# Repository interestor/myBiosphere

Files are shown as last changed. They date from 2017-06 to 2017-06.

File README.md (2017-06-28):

# myBiosphere
It is open source project that make device to make closed ecosystem on a desktop.

parts and material list is here.
http://archive.fabacademy.org/archives/2017/fablabkitakagaya/students/210/final_project.html

<br />

## files 
- code for Arduino[myBiosphere_Arduino.ino]
- code for Processing[myBiosphere_Processing.pde]
- processor boad design
- power board design
- stand's 3d design file
- branch's 3d design file
- island(pod)'s 3d design file
- cap's 3d design file
- heater's mould 3d design file
- ring's 3d design file

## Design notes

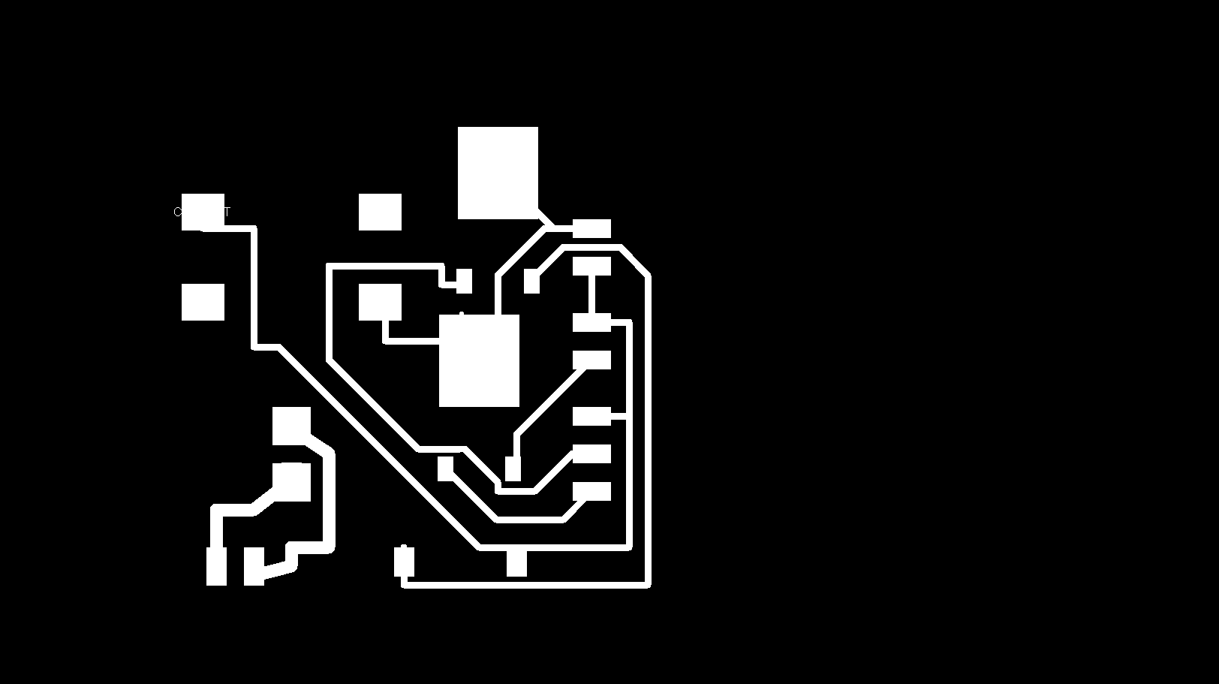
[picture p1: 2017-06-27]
power_boad/output_board_ver3.png

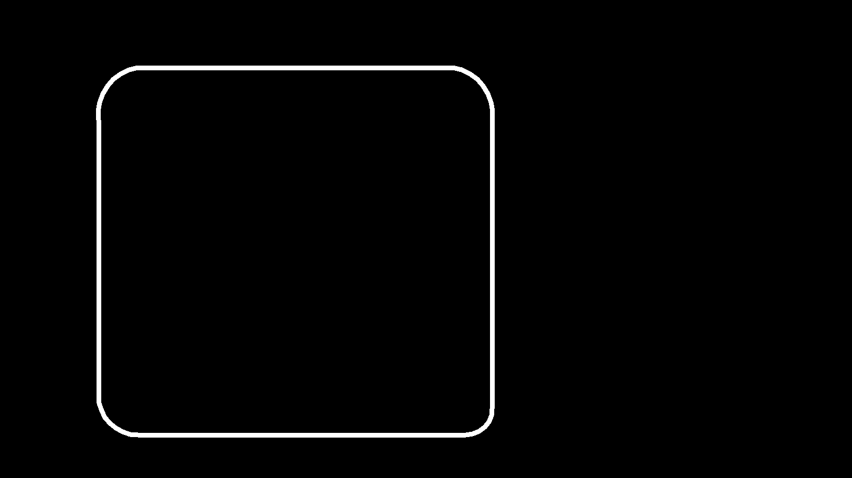
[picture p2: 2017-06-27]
power_boad/output_board_ver3_interior.png

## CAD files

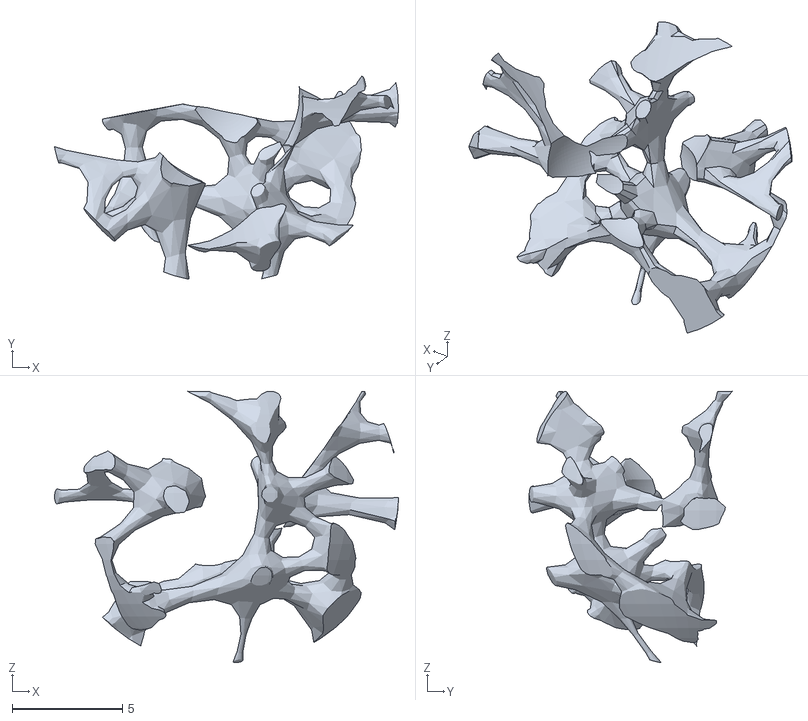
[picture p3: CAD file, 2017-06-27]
branch/branch_7.2cm-16cm_part2.stl
15.6 x 9.22 x 12.3

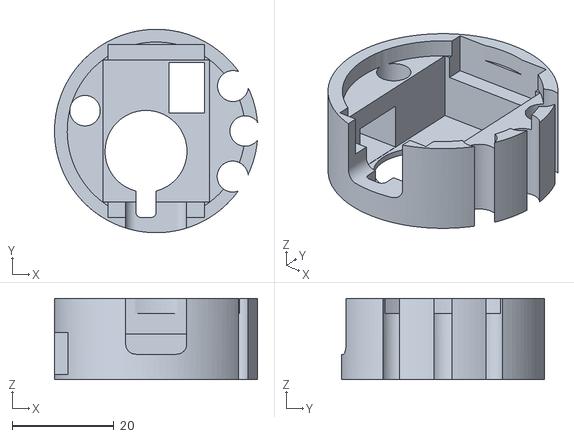
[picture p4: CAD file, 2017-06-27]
cap/sensor_cap_ver6.stl
39.9 x 40.0 x 16.0

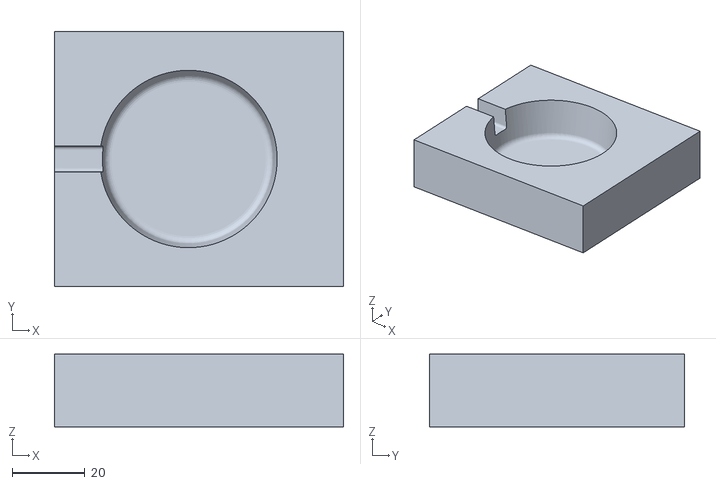
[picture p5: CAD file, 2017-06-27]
heater_mould/heater_mould.stl
79.2 x 70.0 x 20.0

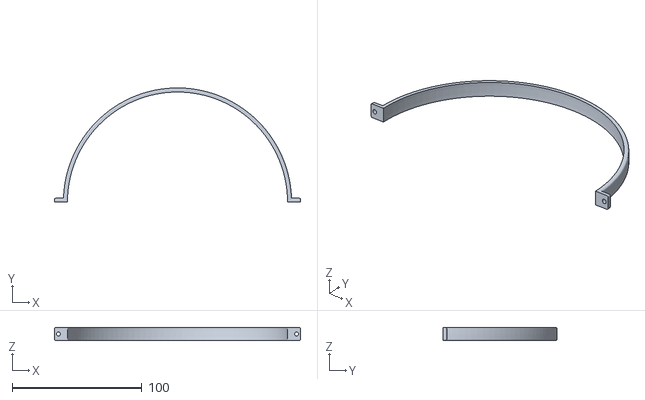
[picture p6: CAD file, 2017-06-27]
ring/equator_0.stl
189.7 x 88.0 x 10.0

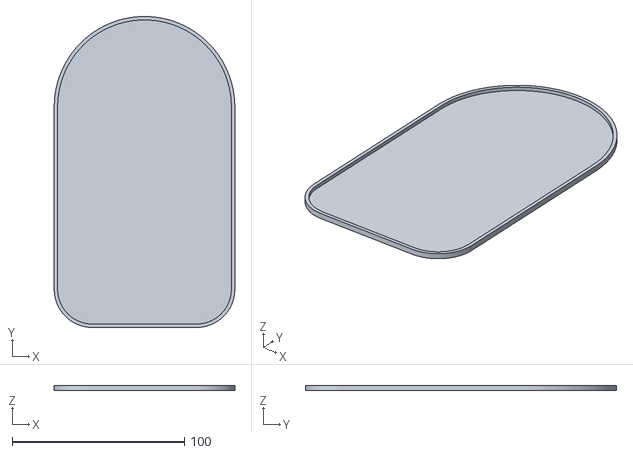
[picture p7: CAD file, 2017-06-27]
stand/stand_buttom.stl
105.0 x 180.8 x 3.03

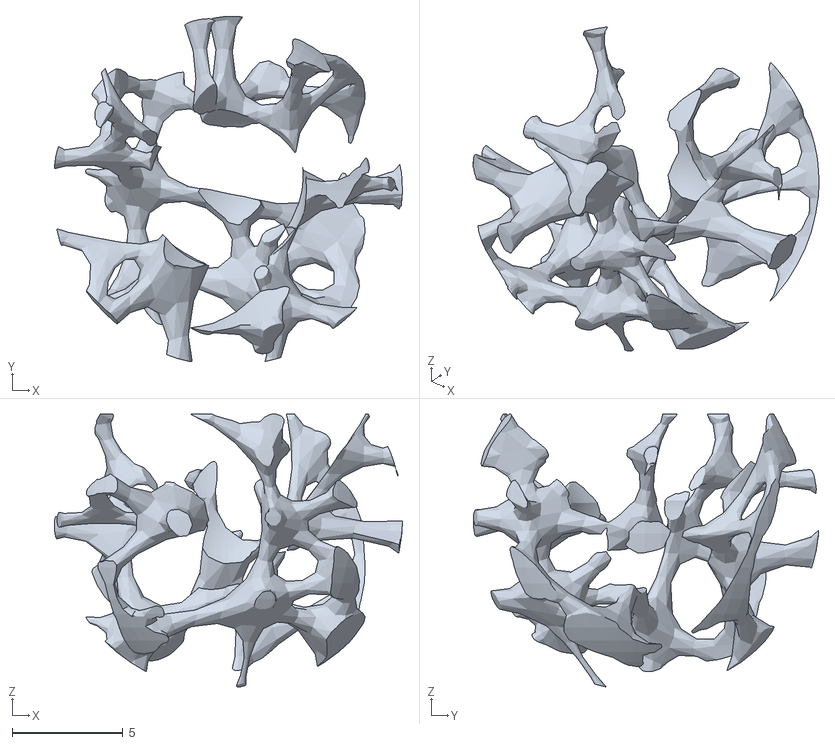
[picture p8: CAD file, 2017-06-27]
branch/branch_7.2cm-16cm.stl
15.7 x 15.6 x 12.3

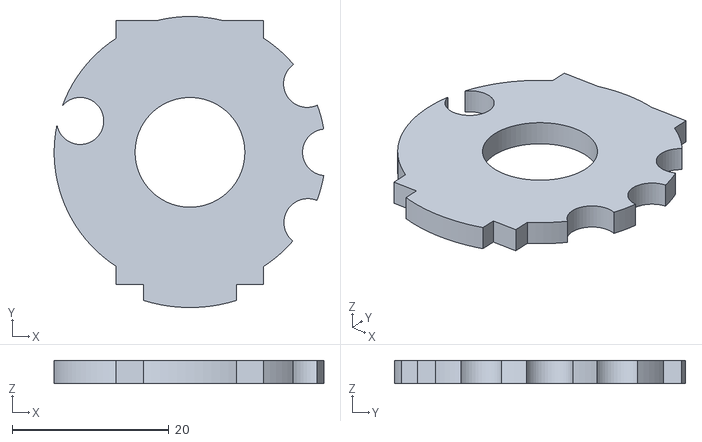
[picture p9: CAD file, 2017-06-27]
cap/sensor_cap_cap_ver6.stl
34.4 x 37.1 x 2.97

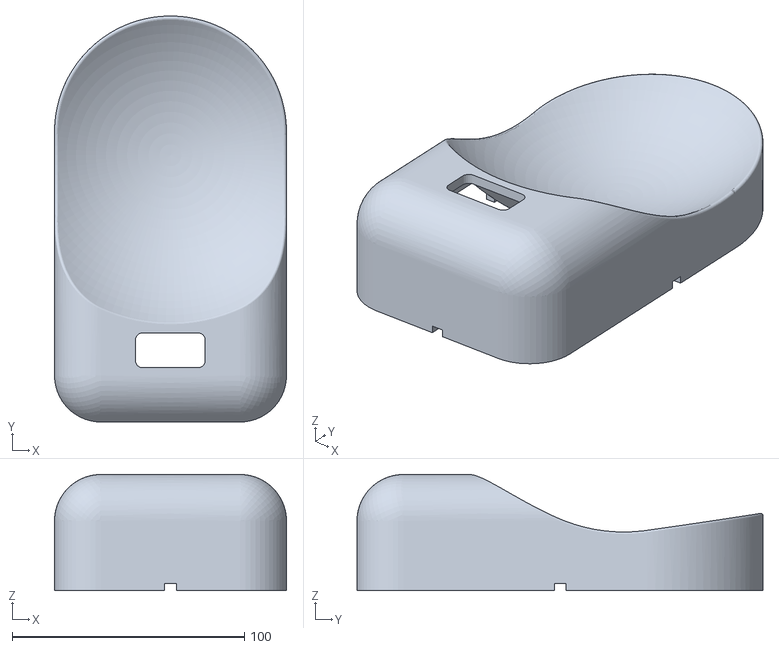
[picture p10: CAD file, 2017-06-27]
stand/stand_ver6.stl
100.0 x 175.0 x 50.0

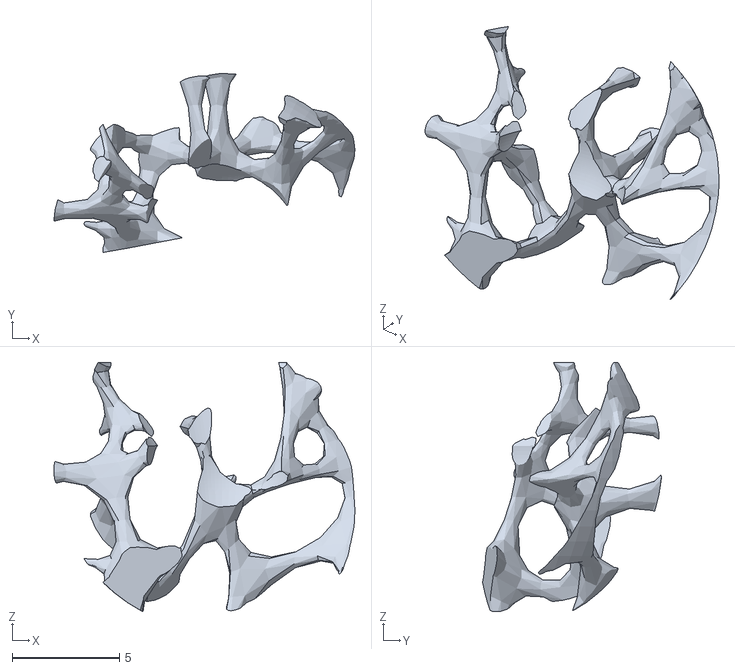
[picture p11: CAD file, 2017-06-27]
branch/branch_7.2cm-16cm_part1.stl
14.0 x 8.35 x 11.6

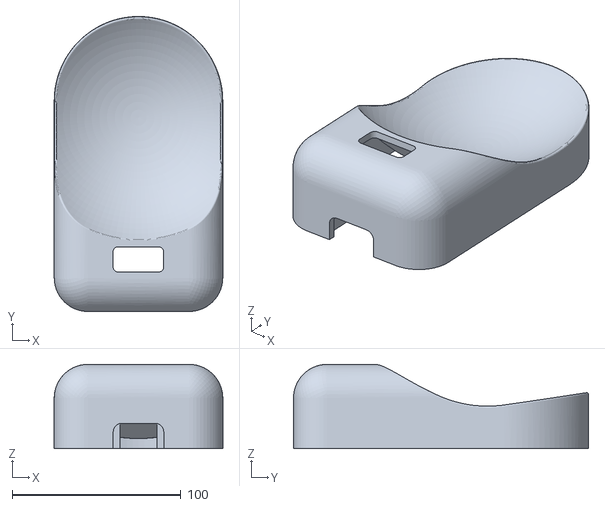
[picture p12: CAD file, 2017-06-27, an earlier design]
stand/stand_ver5.stl
100.0 x 175.0 x 50.0

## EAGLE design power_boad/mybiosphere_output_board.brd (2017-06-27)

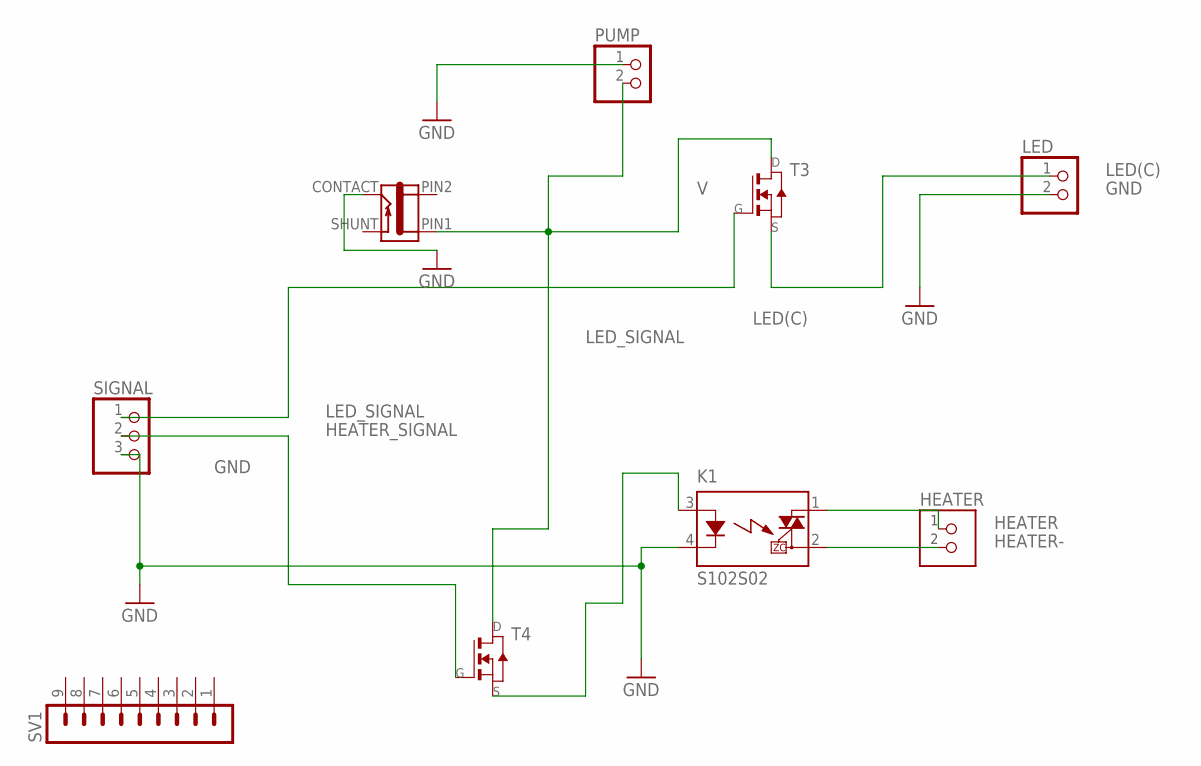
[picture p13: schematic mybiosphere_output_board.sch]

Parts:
HEATER: TERM-1X02-FABLAB; ED555DS-2DS
J1: JACK-2.1MM; PJ-002AH-SMT
K1: S102S02; S202S02
LED: PINHD-1X2/90; 1X02/90
PUMP: PINHD-1X2/90; 1X02/90
SIGNAL: PINHD-1X3; 1X03
SV1: MA09-1
T3, T4: NMOSFETTO252; TO252

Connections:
GND: J1.CONTACT, K1.4 (K), LED.2, PUMP.1, SIGNAL.3
HEATER: HEATER.1, K1.1 (DS1)
HEATER-: HEATER.2, K1.2 (DS2)
HEATER_SIGNAL: SIGNAL.2, T4.1 (G)
LED(C): LED.1, T3.2 (S)
LED_SIGNAL: SIGNAL.1, T3.1 (G)
unnamed: K1.3 (A), T4.2 (S)
PIN2: J1.PIN2
SHUNT: J1.SHUNT
V: J1.PIN1, PUMP.2, T3.3 (D), T4.3 (D)

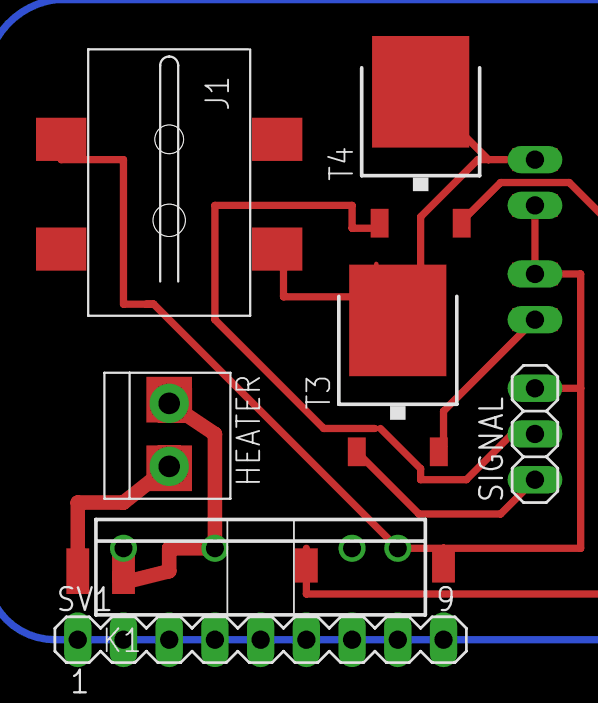
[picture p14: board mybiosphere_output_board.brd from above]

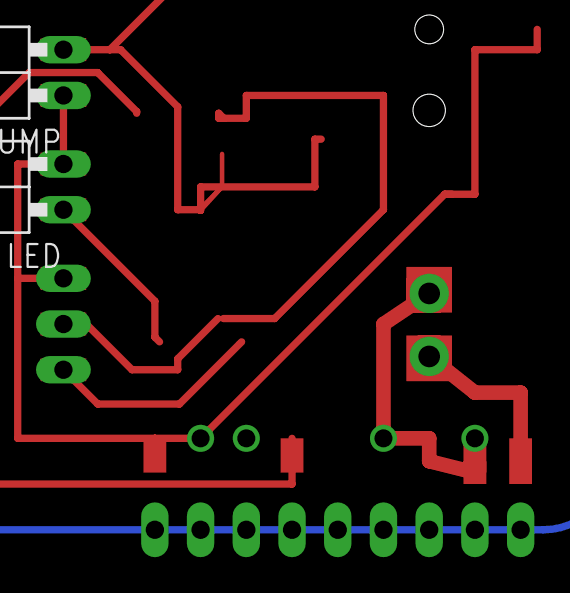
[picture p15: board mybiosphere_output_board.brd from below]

Board: 2 copper layers, 9 parts (2 on the bottom side), 8 nets.

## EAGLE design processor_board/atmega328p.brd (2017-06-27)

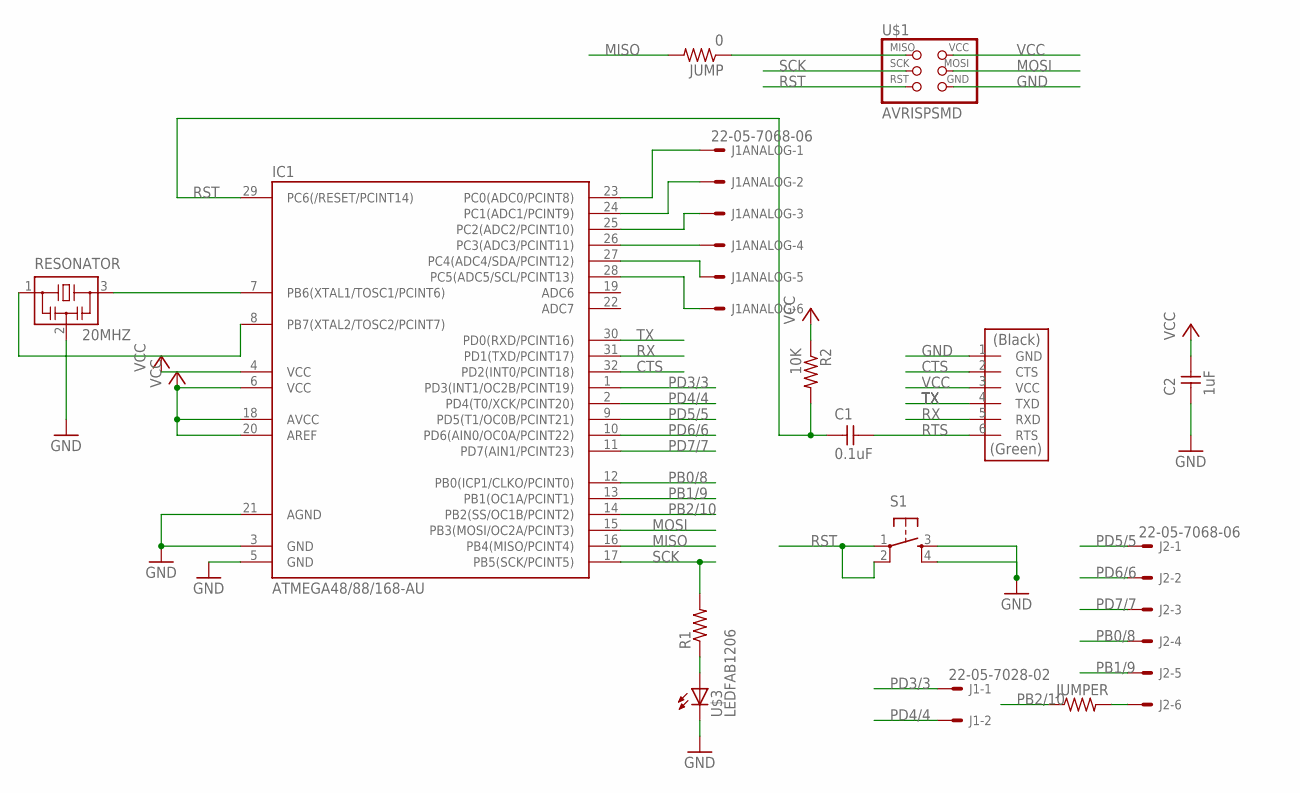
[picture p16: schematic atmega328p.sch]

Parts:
C1: 0.1uF; C1206FAB
C2: 1uF; C1206FAB
IC1: ATMEGA48/88/168-AU; TQFP32-08
J1: 22-05-7028-02; 7395-02
J1ANALOG, J2: 22-05-7068-06; 7395-06
JUMP: 0; R1206FAB
JUMPER: RES-US1206FAB; R1206FAB
R1: RES-US1206FAB; R1206FAB
R2: 10K; R1206FAB
RESONATOR: 20MHZ; EFOBM
S1: 6MM_SWITCH6MM_SWITCH; 6MM_SWITCH
U$1: AVRISPSMD; 2X03SMD
U$2: FTDI-SMD-HEADER; 1X06SMD
U$3: LEDFAB1206; LED1206FAB

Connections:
CTS: IC1.32 (PD2(INT0/PCINT18)), U$2.2 (CTS)
GND: C2.1, IC1.3 (GND), IC1.5 (GND), IC1.21 (AGND), RESONATOR.2, S1.3 (S), S1.4 (S1), U$1.6 (GND), U$2.1 (GND), U$3.2 (C)
MISO: IC1.16 (PB4(MISO/PCINT4)), JUMP.2
MOSI: IC1.15 (PB3(MOSI/OC2A/PCINT3)), U$1.4 (MOSI)
unnamed: IC1.7 (PB6(XTAL1/TOSC1/PCINT6)), RESONATOR.3
unnamed: IC1.8 (PB7(XTAL2/TOSC2/PCINT7)), RESONATOR.1
unnamed: JUMP.1, U$1.1 (MISO)
unnamed: J2.6, JUMPER.2
unnamed: IC1.23 (PC0(ADC0/PCINT8)), J1ANALOG.1
unnamed: R1.1, U$3.1 (A)
unnamed: IC1.24 (PC1(ADC1/PCINT9)), J1ANALOG.2
unnamed: IC1.25 (PC2(ADC2/PCINT10)), J1ANALOG.3
unnamed: IC1.26 (PC3(ADC3/PCINT11)), J1ANALOG.4
unnamed: IC1.27 (PC4(ADC4/SDA/PCINT12)), J1ANALOG.5
unnamed: IC1.28 (PC5(ADC5/SCL/PCINT13)), J1ANALOG.6
PB0/8: IC1.12 (PB0(ICP1/CLKO/PCINT0)), J2.4
PB1/9: IC1.13 (PB1(OC1A/PCINT1)), J2.5
PB2/10: IC1.14 (PB2(SS/OC1B/PCINT2)), JUMPER.1
PD3/3: IC1.1 (PD3(INT1/OC2B/PCINT19)), J1.1
PD4/4: IC1.2 (PD4(T0/XCK/PCINT20)), J1.2
PD5/5: IC1.9 (PD5(T1/OC0B/PCINT21)), J2.1
PD6/6: IC1.10 (PD6(AIN0/OC0A/PCINT22)), J2.2
PD7/7: IC1.11 (PD7(AIN1/PCINT23)), J2.3
RST: C1.1, IC1.29 (PC6(/RESET/PCINT14)), R2.2, S1.1, S1.2 (P1), U$1.5 (RST)
RTS: C1.2, U$2.6 (RTS)
RX: IC1.31 (PD1(TXD/PCINT17)), U$2.5 (RXD)
SCK: IC1.17 (PB5(SCK/PCINT5)), R1.2, U$1.3 (SCK)
TX: IC1.30 (PD0(RXD/PCINT16)), U$2.4 (TXD)
VCC: C2.2, IC1.4 (VCC), IC1.6 (VCC), IC1.18 (AVCC), IC1.20 (AREF), R2.1, U$1.2 (VCC), U$2.3 (VCC)

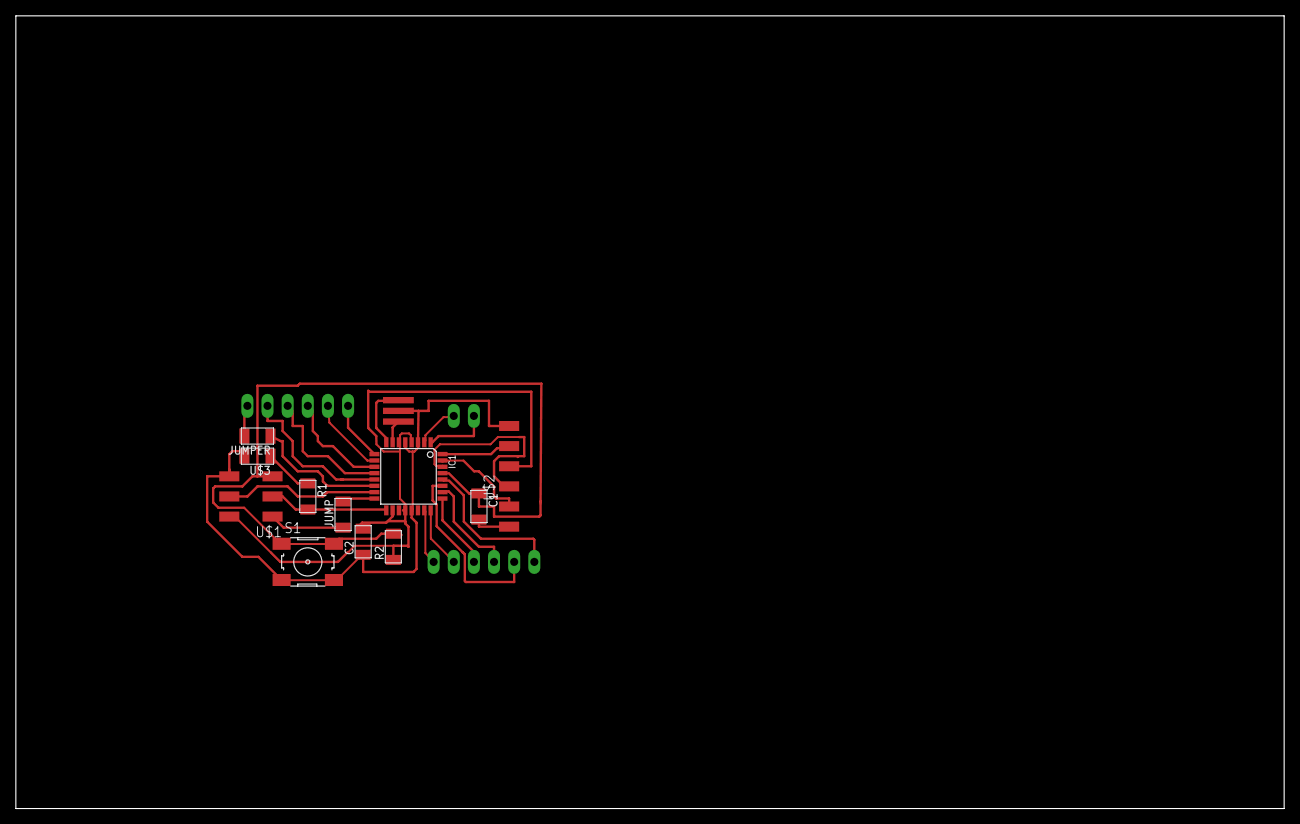
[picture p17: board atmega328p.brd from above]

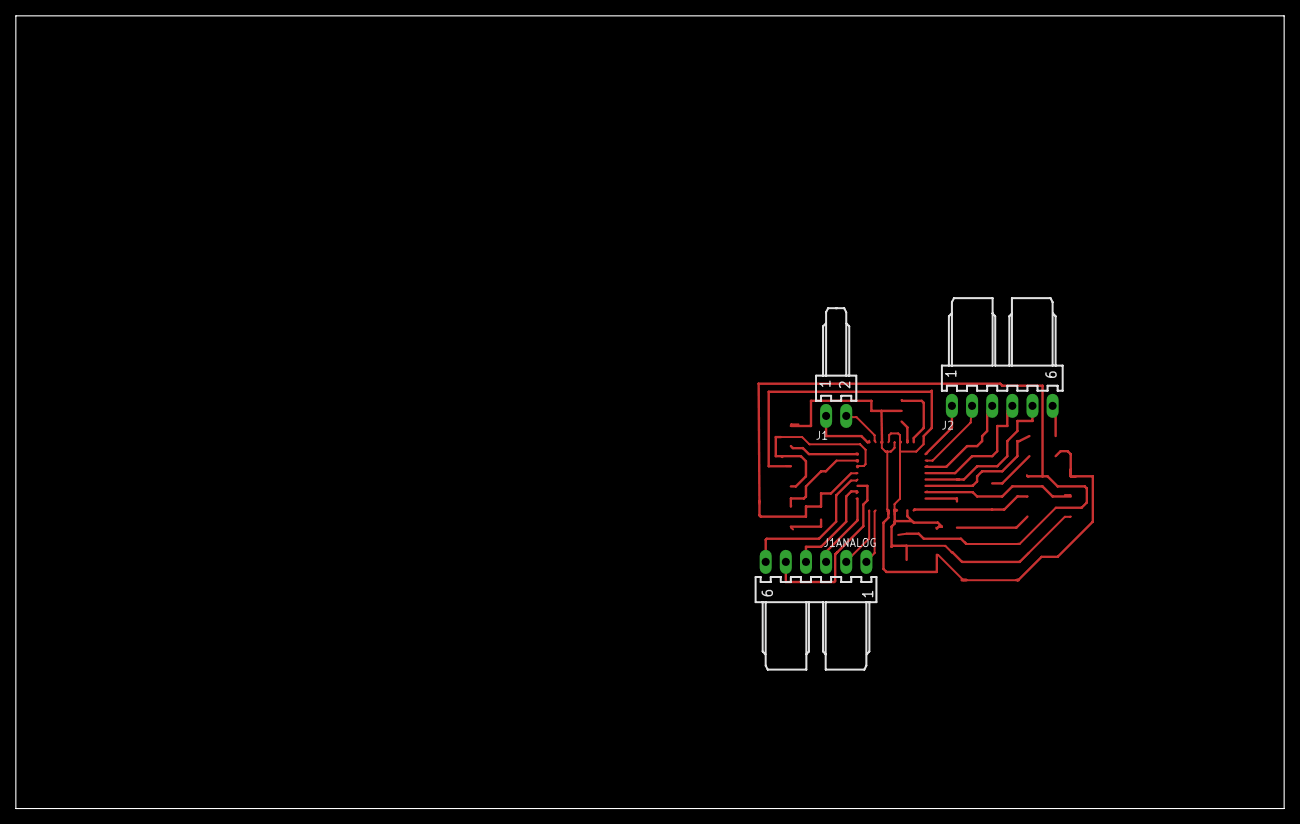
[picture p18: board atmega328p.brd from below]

Board: 2 copper layers, 160.0 x 100.0 mm, 15 parts (3 on the bottom side), 29 nets.

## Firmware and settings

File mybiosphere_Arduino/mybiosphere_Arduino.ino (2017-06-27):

#define TEMP_SENSORPIN  (2)
#define LIGHT_SENSORPIN  (1)
#define LED_PIN 4
#define CO2_PWM 3 //CO2
#define HEATER_PIN (5)


int temp_val = 0;
float B=3435,T0=298.15,R0=10.0,R1=3.25,rr1,t;//for temprature

float v = 5;
float temp = 0;
float heat_on = 35;
float heat_off = heat_on + 100;
int light_on = 40;
int light_off = 40;
int break_co2_loop;

//for CO2
int prevVal = LOW;
long th, tl, h, l, ppm;

String recieve= "22.4,0,0,0";

void setup() {
  Serial.begin(9600);
  pinMode(LED_PIN, OUTPUT);
  pinMode(CO2_PWM, INPUT);
  pinMode(HEATER_PIN,OUTPUT);
    pinMode(13,OUTPUT);//////////////////test
  ppm=0;
}

void loop() {

 
 
 //mesuare temprature by AT-103
  temp_val = analogRead(TEMP_SENSORPIN);
  rr1=R1*temp_val/(1024.0-temp_val);
  t=1/(log(rr1/R0)/B+(1/T0));
  temp=(t-273.15);
 

  //mesure light by cds

  int light_val = analogRead( LIGHT_SENSORPIN );
  int light  = map(light_val, 0, 100, 0, 1023);


  //mesure CO2
  

  break_co2_loop=0;
  while( break_co2_loop < 2 ){

    long tt = millis();
    int myVal = digitalRead(CO2_PWM);

    if (myVal == HIGH) {
      if (myVal != prevVal) {
        h = tt;
        tl = h - l;
        prevVal = myVal;
      }
    }  
    else {
      if (myVal != prevVal) {
        l = tt;
        th = l - h;
        prevVal = myVal;
        ppm = 5000 * (th - 2) / (th + tl - 4);
        break_co2_loop++;
        if(break_co2_loop==2){
          
          Serial.print("temp,");//どこに入れる？
          Serial.print(temp);
          Serial.print(",");
          Serial.print("light,");
          Serial.print(light);
          Serial.print(",");
          Serial.println("CO2 ," + String(ppm));
        }
      }
    }
  }


///recieve threshold

while (Serial.available()) { // If data is available to read,
  recieve  = Serial.readStringUntil(';'); // read it and store it in val
 
  char recieve_c[255];
  recieve.toCharArray(recieve_c, 255);//文字列操作のためchar型に変換
  
  //,で分割してcharに格納
  char *heat_on_c = strtok(recieve_c,",");
  char *heat_off_c = strtok(NULL,",");  //2回目以降は第一引数はNULL
  char *light_on_c = strtok(NULL,","); 
  char *light_off_c = strtok(NULL,","); 

  
  //Serial.println(heat_on_c);//for debug
  //Serial.println(heat_off_c);
  //Serial.println(light_on_c);
  //Serial.println(light_off_c);
 
 //char からfloatに変換 
  heat_on = atof(heat_on_c);
  heat_off = atof(heat_off_c);
  light_on = atof(light_on_c);
  light_off = atof(light_off_c);

 delay(100); // Wait 100 milliseconds for next reading
   
 }
 
 
 
  //swich light
  if (light < light_on ) {//if light sensor val shows  daker than light_on threshold 
    digitalWrite(LED_PIN, HIGH);
  }
  else{
      digitalWrite(LED_PIN, LOW);
    }

  //swich heater
  if (temp < heat_on ) {//if temprature cooler than heat_on threshold 
    digitalWrite(HEATER_PIN, HIGH);
  }
  else{
    if(temp > heat_off){
      digitalWrite(HEATER_PIN, LOW);
    }
  }


}

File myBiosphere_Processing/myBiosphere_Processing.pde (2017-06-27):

import processing.serial.*;//import serial library
Serial myPort;//make instance named myPort

BufferedReader reader;//for read csv
String line; 

String datastr;  // data for write csv
PrintWriter output;  // PrintWriterobject for write csv


//GUI parts location varieble
int light_y_location=80*6;
int heater_y_location=80*7;
int onbox_x_location=300;
int offbox_x_location=500;
int input_location_x;
int input_location_y;


//varieble of setting  threshold 
String heart_on="22.4";
String heart_off="";
String light_on="";
String light_off="";


String light_val="0";
String temp_val="0";
String CO2_val="0";

int which_box_click;
String keys;
String submit;

int day_diff;
PImage light_img;
PImage temp_img;
PImage CO2_img;

void setup() {
  size(700, 700);//window size
  
  light_img = loadImage("light.png");
  temp_img = loadImage("temp.png");
  CO2_img = loadImage("CO2.png");

  
  //set Serial 
  //println(Serial.list());  // 使えるポート一覧。下記ポートをSerial.list()[0]に書き換えると自動でシリアルポートが選択される（自分は二番だったのでマニュアル指定した）
  myPort = new Serial(this, "/dev/tty.usbserial-A4001CMh", 9600);//Serial port setting.Write your Serial port name appear in Arduino tool.
  myPort.clear();
  
  keys = new String();//テキストボックス用。複数文字の入力ができるようにkeysという文字列変数を作る
  
    //show how long myBiosphere keep
  reader = createReader("myBiosphere_log.csv");//open csv file
  line=null;
  try {
    line = reader.readLine();//1行読む
  } 
  catch (IOException e) {//エラー処理
    e.printStackTrace();
    println("read error");
  }

/*   
 String[] co = split(line, ','); // , で分割して日にちの情報だけどり出す
 String[] yyyymmdd = split(co[0], '/');// /で分割して年、月、日にちをわける
 println(co[0]);
 int mon_to_days[]={0,0,31,59,90,120,151,181,212,243,273,304,334,365,396};//その月までの経過日数

  //記録し始めた日までの経過日数
 int year1=int(yyyymmdd[0]);
 int month1=int(yyyymmdd[1]);
 int day1=int(yyyymmdd[2]);
 int dy1= (year1-1)*365;
 int dl1 = year1 / 4 - year1 / 100 + year1 / 400;//うるう年
 int dm1 = mon_to_days[month1];
 int d1 = day1;
 int start_days= dy1 + dl1 + dm1 + d1-1;//1年1月1日から始めた年までの経過日数
 
  //今日までの経過日数
 int now_year=year();
 int now_month=month();
 int now_day=day();
 int now_dy= (now_year-1)*365;
 int now_dl = now_year / 4 - now_year / 100 + now_year / 400;//うるう年
 int now_dm = mon_to_days[now_month];
 int now_d = now_day;
 int now_days= now_dy + now_dl + now_dm + now_d-1;//1年1月1日から今日までの経過日数
 
 day_diff=now_days - start_days;
 
 // make and open log file to write
 output = createWriter("myBiosphere_log.csv");  
*/ 
   
 
}

void draw() {
  //draw background color
  background(255, 255, 255);
  fill(218,235,0);
  noStroke();
  rect(0,0,width,80*1.5);
  fill(200,200,200);
  rect(0,80*5,width,height);
  

  //draw text (text,x, y)
  fill(255,255,255);
  textSize(20);
  text("This biosphere keeps",160,80);
  textAlign(CENTER);
  text("days",width/2+160,80);

  fill(0,0,0);
  textSize(50);
  text(day_diff,width/2,80);
  
  fill(0,0,0);
  textSize(16);
  text("Illumination",width/2-50, 80*2+40);
  text("temprature", width/2-50, 80*3+40);
  text("CO2", width/2-50, 80*4+40);
  
  image(light_img, width/2-200, 80*2-25+40);
  image(temp_img, width/2-200+8, 80*3-25+40);
  image(CO2_img, width/2-200, 80*4-25+40);
  
  
 
  textSize(16);
  text("setting", 100, 80*5+40);
  text("light", 180, light_y_location);
  text("on", onbox_x_location-50, light_y_location);
  text("off", offbox_x_location-50, light_y_location);
  text("heater", 180, heater_y_location);
  text("on", onbox_x_location-50, heater_y_location);
  text("off", offbox_x_location-50, heater_y_location);

  fill(255, 255, 255);//color of box
  rect(onbox_x_location, light_y_location-20, 60, 21);
  rect(offbox_x_location, light_y_location-20, 60, 21); 
  rect(onbox_x_location, heater_y_location-20, 60, 21);
  rect(offbox_x_location, heater_y_location-20, 60, 21);


  //draw valu at that time
  textSize(40);
  fill(0, 0, 0);//color of text
  text(light_val + " ", width/2+100, 80*2+8+40);//change value every cycle
  text(temp_val, width/2+100+3, 80*3+8+40);//change value every cycle
  text(CO2_val, width/2+100, 80*4+8+40);//change value every cycle
  textSize(16);
  text("℃", width/2+200, 80*3+40);
  text("ppm", width/2+200, 80*4+40);
  


  //draw setting text box
  textSize(16);

  text(light_on, onbox_x_location+30, light_y_location);// light on box
  text(light_off, offbox_x_location+30, light_y_location);//lght off box
  text(heart_on, onbox_x_location+30, heater_y_location);// heater on box
  text(heart_off, offbox_x_location+30, heater_y_location);//heater off box  


  //draw submit button
  fill(10, 10, 10);
  rect(160, 80*8-20, 400, 30);
  fill(250, 255, 255);
  text("submit",width/2+15,80*8);
  fill(10, 10, 10);
 

  
  
//read sensor value from arduino
    if ( myPort.available() > 0) {
    //for debug // println("port available");
    delay(1000);
    datastr = myPort.readString();//read data
    String[] datastr_split = splitTokens(datastr,",");
    temp_val = datastr_split[1];
    light_val = datastr_split[3];
    CO2_val = datastr_split[5];
    //println(temp_val);for debug
    //println(light_val);
    //println(CO2_val);
    
 /*   
  //write csv    
    datastr = nf(year(),2)+"/"+nf(month(),2)+"/"+nf(day(),2)+","+nf(hour(),2) + ":" + nf(minute(),2) + ":" + nf(second(),2) + "," + datastr  ;
    output.println(datastr);
    output.flush();  // 出力バッファに残っているデータを全て書き出し
    //    output.close();  // ファイルを閉じる
   //println(datastr); //print in console.
 */   } 
    
}



void mousePressed() {
  //jadge which box is clicked
  //when click light on box
  
keys = "";
  
  if (mouseY>light_y_location-20 && mouseY<light_y_location && mouseX> onbox_x_location && mouseX<onbox_x_location+30) {
    which_box_click=1;
  } else {

    //when click light off box
    if (mouseY>light_y_location-20 && mouseY<light_y_location && mouseX> offbox_x_location && mouseX<offbox_x_location+30) {
      which_box_click=2;
    } else {

      //when click heater on box
      if (mouseY>heater_y_location-20 && mouseY<heater_y_location && mouseX> onbox_x_location && mouseX<onbox_x_location+30) {
        which_box_click=3;
      } else {

        //when click heater off box
        if (mouseY>heater_y_location-20 && mouseY<heater_y_location && mouseX> offbox_x_location && mouseX<offbox_x_location+30) {
          which_box_click=4;
        } else {
          //when click background 
          which_box_click=0;

        }
      }
    }
  }
}
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

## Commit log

2017-06-27 Add initial files
    Add design files.These are files when I presented Fabacademy 2017.
    [atmega328p.brd, atmega328p.sch, branch_7.2cm-16cm.stl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]
2017-07-11 Add top_hole.ai
    Add file for ease cut top hole

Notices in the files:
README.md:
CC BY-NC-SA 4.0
